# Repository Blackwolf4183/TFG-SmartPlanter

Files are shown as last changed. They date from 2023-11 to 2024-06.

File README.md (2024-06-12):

## Proyecto SmartPlanter

Este README proporciona una visión general del proyecto **SmartPlanter**, que combina tecnologías IoT, cloud computing y machine learning para crear una maceta inteligente con riego automático y monitorización a través de una interfaz web.

## Tabla de Contenidos

- [Sobre el Proyecto](#sobre-el-proyecto)
  - [Objetivos](#objetivos)
  - [Características](#características)
  - [Especificaciones Técnicas](#especificaciones-técnicas)
- [Construido Con](#construido-con)
- [Guía de Inicio](#guía-de-inicio)
  - [Prerequisitos](#prerequisitos)
  - [Instalación](#instalación)
- [Uso](#uso)
- [Roadmap](#roadmap)
- [Licencia](#licencia)
- [Contacto](#contacto)

---

<br />
<div align="center">
  <a href="https://github.com/Blackwolf4183/TFG-SmartPlanter">
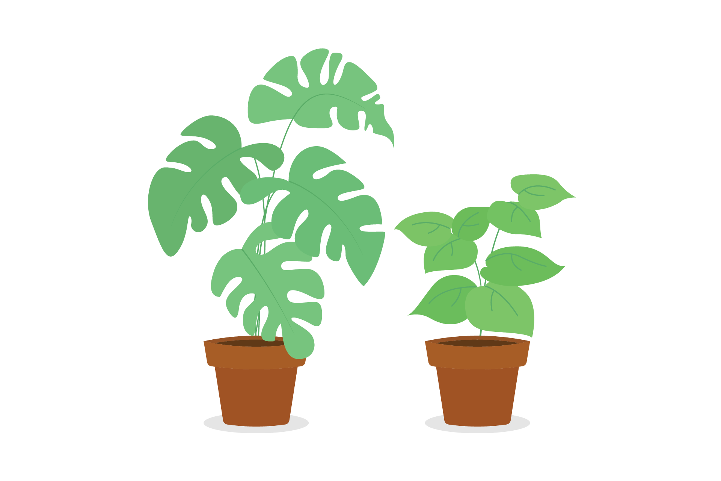
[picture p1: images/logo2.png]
    
  </a>

## Sobre el Proyecto

### Objetivos

El proyecto **SmartPlanter** tiene como objetivo crear una maceta IoT que permite:

- **Riego Automático**: Utiliza sensores para detectar la humedad del suelo y activar el riego cuando sea necesario.
- **Monitorización Remota**: Ofrece una interfaz web para visualizar en tiempo real los datos de la planta como temperatura, luz y humedad.
- **Interfaz Web**: Proporciona una plataforma accesible para configurar y controlar la maceta desde cualquier lugar.

### Características

- **Sensores Integrados**: Monitorea luz, temperatura, humedad del aire y del suelo.
- **Control Automático**: Sistema de riego basado en el análisis de datos en tiempo real.
- **Notificaciones y Alertas**: Envía alertas al usuario sobre el estado de la planta.
- **Machine Learning**: Utiliza modelos predictivos para optimizar el riego y el cuidado de la planta.

### Especificaciones Técnicas

- **Microcontrolador**: ESP32.
- **Plataforma Cloud**: Azure IoT Hub.
- **Base de Datos**: Supabase para el almacenamiento de datos.
- **Lenguajes de Programación**: Python y JavaScript.
- **Frameworks**: Next.js y React.js para la interfaz web.
- **Hardware**: Sensores de humedad, temperatura, y luz.

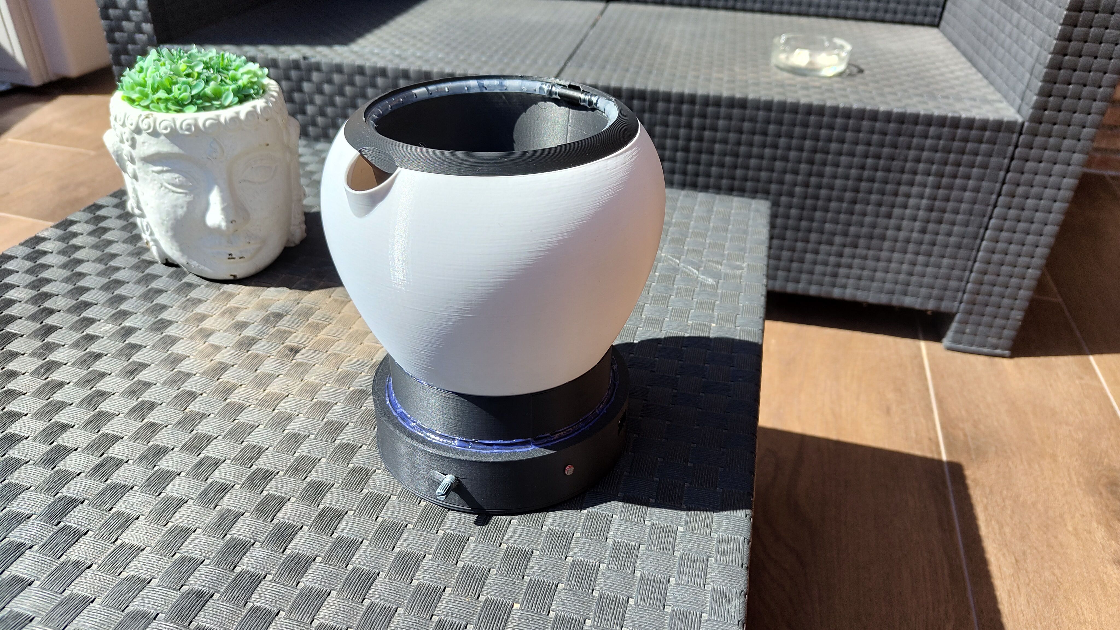
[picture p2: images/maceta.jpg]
Product Name Screen Shot
[](https://example.com)
---

## Construido Con

- [Next.js](https://nextjs.org/) - Framework para React
- [React.js](https://reactjs.org/) - Librería JavaScript para construir interfaces de usuario
- [Python](https://www.python.org/) - Lenguaje de programación para el backend
- [Azure IoT Hub](https://azure.microsoft.com/en-us/services/iot-hub/) - Plataforma de nube para IoT
- [ESP32](https://www.espressif.com/en/products/socs/esp32) - Microcontrolador
- [Supabase](https://supabase.io/) - Base de datos de código abierto

---

## Guía de Inicio

Para obtener una copia local del proyecto y ejecutarlo, sigue estos pasos:

### Prerequisitos

- Node.js y npm (Node Package Manager)
- Python 3.x

Instala Node.js y npm:
```sh
npm install npm@latest -g
```

### Instalación

1. Clona el repositorio:
   ```sh
   git clone https://github.com/Blackwolf4183/TFG-SmartPlanter.git
   ```
2. Navega al directorio del proyecto:
   ```sh
   cd TFG-SmartPlanter/WebApp/Frontend
   ```
3. Instala las dependencias:
   ```sh
   npm install
   ```
---

## Uso

Una vez instalado, puedes ejecutar el proyecto localmente:

1. **Inicia el servidor de desarrollo**:
   ```sh
   npm start
   ```
2. **Accede a la interfaz web** a través de tu navegador en `http://localhost:3000`.

Para más ejemplos y capturas de pantalla, consulta la [documentación](https://github.com/Blackwolf4183/TFG-SmartPlanter).

---

## Roadmap

- [ ] Implementación de sensores adicionales
- [ ] Mejora de la interfaz de usuario
- [ ] Integración con otros servicios cloud
- [ ] Funcionalidades avanzadas de machine learning

Consulta la lista de [issues abiertas](https://github.com/Blackwolf4183/TFG-SmartPlanter/issues) para ver una lista completa de las características propuestas y problemas conocidos.

---

## Licencia

Distribuido bajo la Licencia MIT. Para más información, consulta `LICENSE.txt`.

---

## Contacto

Pablo Pérez Martín - perezmartinpablo@uma.es

Link del Proyecto: [SmartPlanter en GitHub](https://github.com/Blackwolf4183/TFG-SmartPlanter)

---

[product-screenshot]: images/maceta.jpg

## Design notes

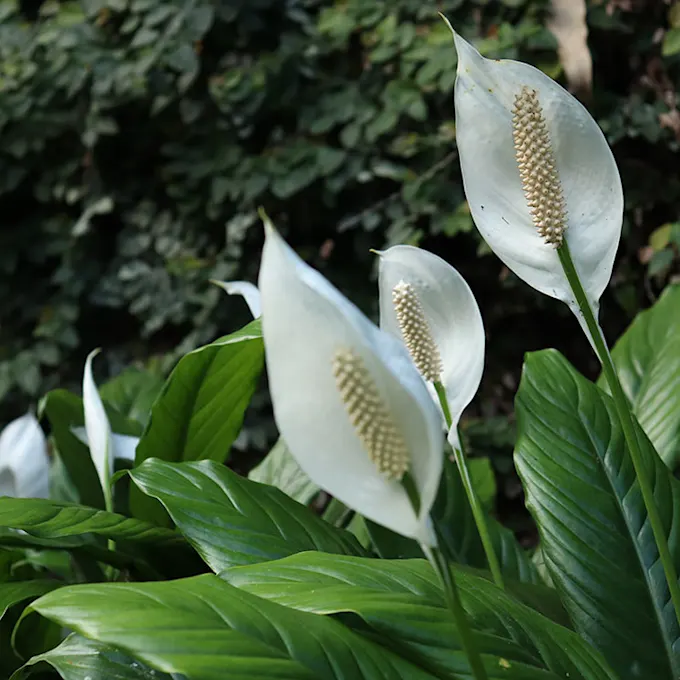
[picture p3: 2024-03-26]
WebApp/Backend/plant_images/espafilito.jpg

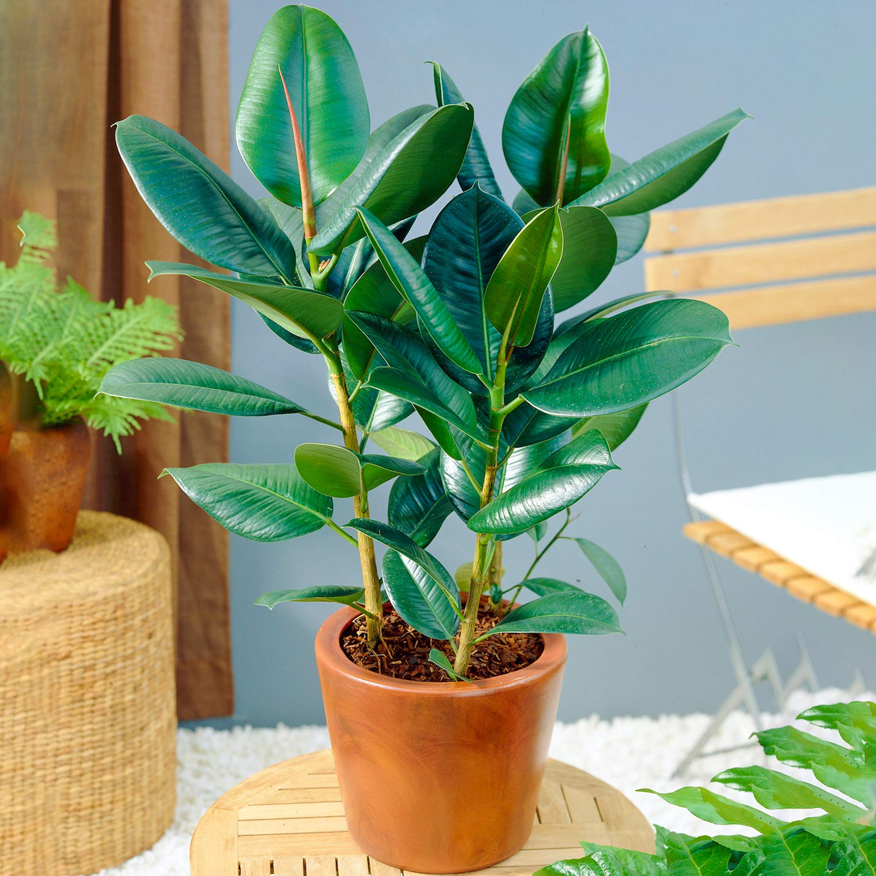
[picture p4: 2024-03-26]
WebApp/Backend/plant_images/ficus_robusta.jpg

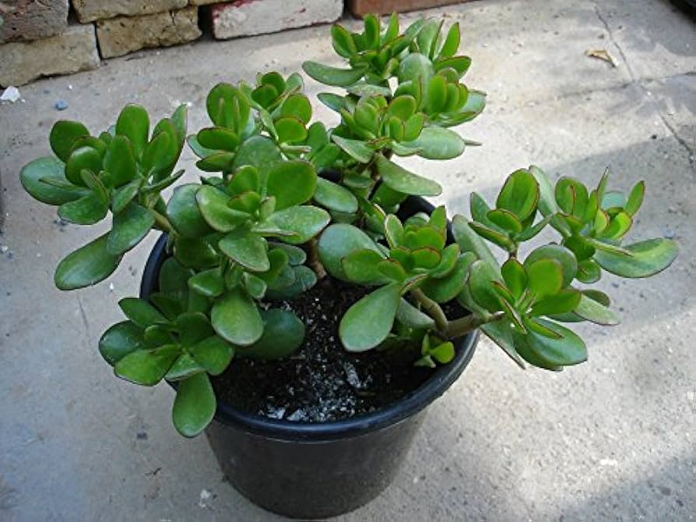
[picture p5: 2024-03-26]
WebApp/Backend/plant_images/arbol_jade.jpg

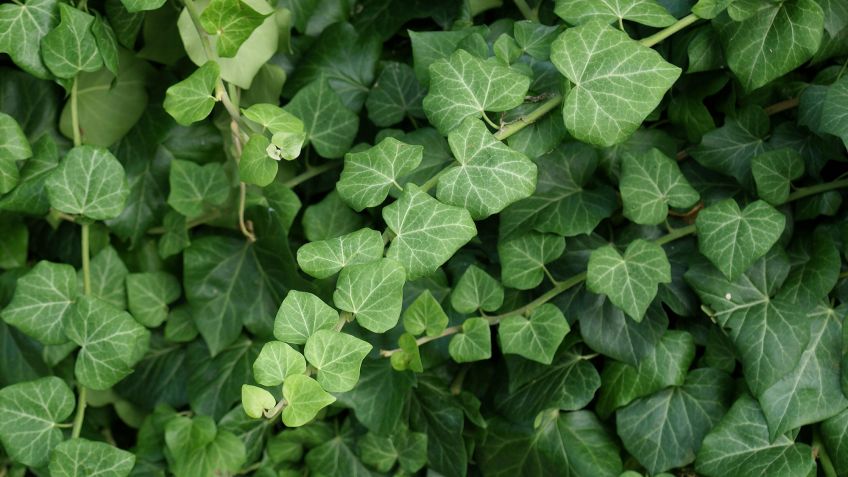
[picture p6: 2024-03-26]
WebApp/Backend/plant_images/hiedrajpg.jpg

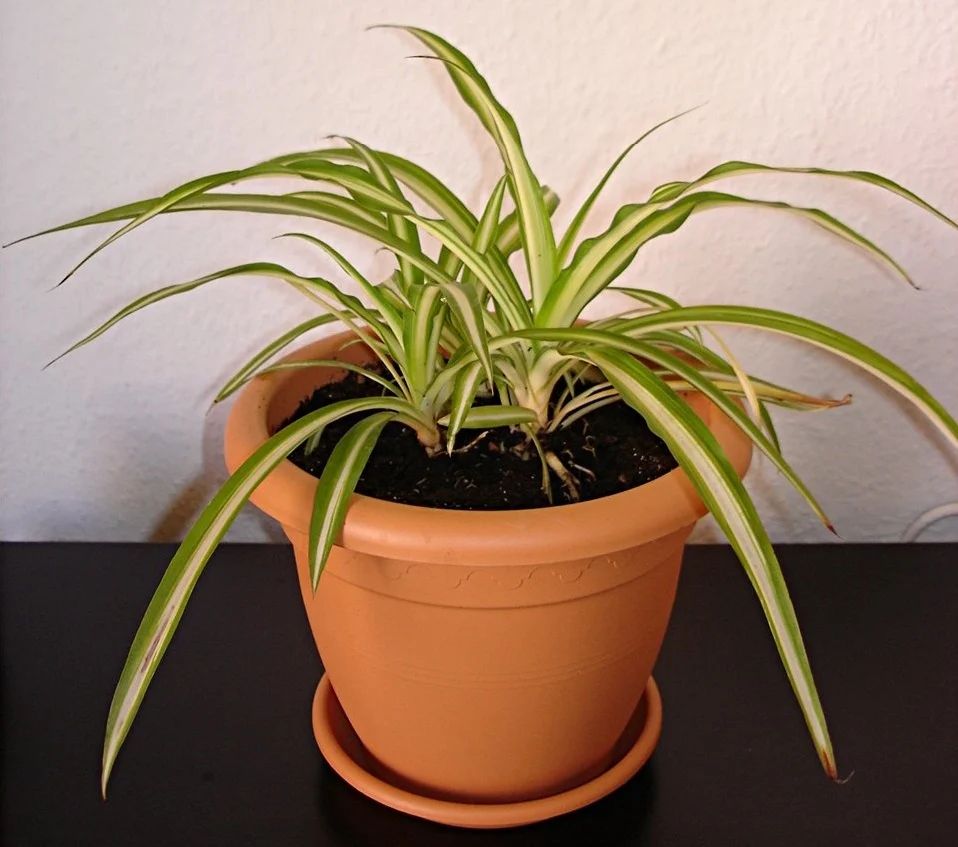
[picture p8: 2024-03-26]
WebApp/Backend/plant_images/malamadre.jpg

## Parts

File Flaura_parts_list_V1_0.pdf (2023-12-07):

Quantity Name | Type | Specification | Additional notes | Example

Parts with water contact
30 cm | Soft Hose Ø4 - Ø2 mm | Material: PVC | outerØ 4 mm, innerØ 2 mm | transparent looks best | https://ebay.us/ntEGVZ
15 cm | Soft Hose Ø7 - Ø5 mm | Material: PVC | outerØ 7 mm, innerØ 5 mm | transparent looks best | https://ebay.us/ntEGVZ
40 cm | Hard Hose Ø4 - Ø2 mm | Material: PTFE, PA?, PU? | outerØ 4 mm, innerØ 2 mm | transparent looks best | https://ebay.us/sQVEkS
1 | T-Connector Hose | T-shape, plastic | outerØ 3.2 mm, innerØ 2.4 mm | Size for link in example is 3.2 mm | https://ebay.us/po10i3
1 | Diaphragm water pump (XYT SP130-XH) | DC 3.7V | Ø20 x 45 mm, Hose connections Ø3.5 mm | 2 visable diaphragms -> suitable for water | https://de.aliexpress.com/item/4000974989453.html?sp (https://de.aliexpress.com/item/4000974989453.html?spm=a2g0x.12010615.8148356.3.2df127f6HkLLrm)
20 mL | Silicon sealant | Sealant for electronics works best (more liquid) | Any, Additional nozzle is very useful | transparent, local hardware store? | https://ebay.us/K84adc

Parts to be soldered

3 | Resistor 100 kOhm | Carbon Film, THT axial | 100 kOhm, 1/4 W | | https://amzn.to/37WaeuK
1 | Resistor 270 Ohm | Carbon Film, THT axial | 270 Ohm, 1/4 W | | https://amzn.to/37WaeuK
1 | Capacitor 100 nF | THT (Pitch 2.54 mm) | 100 nF | | https://ebay.us/KCRTnK
1 | Diode 1N4007 | DO-41, THT | 1 A | | https://ebay.us/PQQNdj
1 | MOSFET IRLZ44N | N-Channel, THT (Pitch 2.54 mm) | Logic level (L) | Don't confuse with : IRFZ44N | https://ebay.us/49aZjN
1 | Push button (XUNPU TS-1002N-08526) | Tactile Switch, THT Side operation | 6 x 7.5 x 8.5 mm, 50 mA | switch lever length: 5 mm | https://lcsc.com/product-detail/Tactile- (https://lcsc.com/product-detail/Tactile-Switches_XUNPU-TS-1002N-08526_C455136.html)
1 | Power switch (SHOU HAN SK12D07VG5) | Toggle Switch, THT Side operation | 4.7 x 8.7 x 9.4 mm, 500 mA | switch lever length: 5 mm | https://lcsc.com/product- (https://lcsc.com/product-detail/Tactile-Switches_XUNPU-TS-1002N-08526_C455136.html) detail/Toggle- (https://lcsc.com/product-detail/Toggle-Switches_SHOU-HAN-SK12D07VG5_C431548.html)
1 | Pin Header Female 12 Pins | THT (Pitch 2.54 mm) | Female, 12 Pins, Height 8.5 mm | | https://ebay.us/DgdD (https://lcsc.com/product-detail/Toggle-Switches_SHOU-HAN-SK12D07VG5_C431548.html)9i
1 | Pin Header Female 16 Pins | THT (Pitch 2.54 mm) | Female, 16 Pins, Height 8.5 mm | | https://ebay.us/DgdD9i
1 | Resistor 33 kOhm | Carbon Film, THT axial | 33 kOhm, 1/4 W | https://amzn.to/37WaeuK

1 | Pin Header Male 3 Pins | THT (Pitch 2.54 mm) | Male, 3 Pins | seperatable into 3 pins | https://ebay.us/TkIBPl
2 | JST Connector Female 2 Pins with Cable | JST Connector Female, PH (Pitch 2.0 mm) | 2 Pins, Cable > 10 cm, AWG24 or AWG22 | Don't use common AWG26 | https://amzn.to/3AY5RMa
1 | JST Connector Female 6 Pins with Cable | JST Connector Female, PH (Pitch 2.0 mm) | 6 Pins, Cable > 30 cm, AWG26 | AWG26 is okay here | https://ebay.us/j6QXjK
2 | JST Connector Male 2 Pins | JST Connector Male, PH (Pitch 2.0 mm) | 2 Pins, Straight | See note on connecter types (last page) | https://amzn.to/3AY5RMa
1 | JST Connector Male 6 Pins | JST Connector Male, PH (Pitch 2.0 mm) | 6 Pins, Straight | See note on connecter types (last page) | https://ebay.us/j6QXjK
1 | Custom PCB (curcuit board) | FR-4, 2 Layers | thickness 1.6 mm, copper weight 1 oz, HASL | custom-made (Gerber file) | Custom PCB manufacturer

Other parts

1 | Li-Ion Battery 3.7V with Connector | 18650 Format, JST Connector Female, PH (Pitch 2.0 mm) | 3.7V, > 2000 mAh, Protection circuitry included | | https://www.adafruit.com/pr
22 | Self tapping Screw Ø3 x 8
mm

Thread forming screw for
thermoplatic (e.g. DIN 9091)
Ø3 x 8 mm, Pan head | https://ebay.us/V4vZwn

oduct/1781 (https://www.adafruit.com/product/1781)

1 | Microcontroller ESP32 | Wemos LOLIN 32 Development board | not the "lite" or "pro" variants, ME6211 LDO | Look at the next page of this file
1 | Capacitve Soil Moisture Sensor | Capacitve Soil Moisture Sensor v1.2 | TL555Q/C/I timer chip, 662K LDO | Look at the next page of this file

Optional
1 | Planter | upperØ 110 mm, lowerØ 85 mm,
| | height 90 mm

Local gardening store

Most things you can currently find in online shops are imitations that look the same at first glance, but some have cheaper electronic components soldered on and do not work properly.

When ordering, it is very important to look carefully at the product images and to check the markings on the electronic components on the circuit board.
If the image quality is so poor, that you cant read the markings - DO NOT ORDER from this store.
If the markings are the ones we are looking for: ask the the store to confirm these markings.

It happend to me, that I didnt recive the exact product as shown in the product pictures, but a diffrent one with the wrong electronic components on it. Even if I ordered from a store from which I initially received a suitable product, I sometimes received a different product with the second order.
I didn't include a link for the ESP32 microcontroller and capacitive soil moisture sensor because I had some bad experiences when ordering them and I don't want to be responsible if this happens to others.

Here's what to look for with each component:

Wemos LOLIN 32 Development board
watch out for undersized LDO's and JST PH connector (watch my Youtube video for more details), https://www.youtube.com/watch?v=GNNzLwCidCE
Good markings: S2RY, S2RK, S2MD, S2PC, S2SL, S2TD (thats an ME6211 LDO)
Bad markings: 4A**, 4B** (thats an XC6204 or XC6205 LDO)

Capacitve Soil Moisture Sensor
watch out for correct 555 Timer chip, present 662k LDO and correct positioning of via hole (watch my Youtube video for more details) https://www.youtube.com/watch?v=IGP38bz-K48
Good markings: TL555C, TL555Q, TL555I
Bad markings: NE555

If you don't want to order all parts individually: I'm thinking of offering all the parts for Flaura as a kit in the future if enough people are interested. To find out, I created a short Google form that you can fill out if you would like to buy such a kit. https://docs.google.com/forms/d/1GDRpVRxuvAgHPNp1CEXVgIKZr3mZhqmVqcmtKoSlDA8

Note on connecter types:
Globally speaking, there seem to be different opinions what male and female connectors are, also among sellers of these parts.

Better make sure the product you want to buy matches those in my videos.

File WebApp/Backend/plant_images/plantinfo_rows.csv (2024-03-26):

id | perenualid | commonname | scientificname | imageurl | watering | sunlight | plantdescription | carelevel | mintemperature | maxtemperature
1 | 7168 | Lengua de trigre | Dracaena trifasciata | https://i.ibb.co/JqQmkMh/lengua-tigre.png | MODERATE | Luz indirecta media a brillante | La Lengua de Tigre (Sansevieria trifasciata) es una planta herbácea perenne conocida por sus hojas puntiagudas y su patrón de rayas distintivo que se asemeja a la piel de un tigre. Es una planta fácil de cuidar y tolerante a condiciones de poca luz y sequía. Su capacidad para purificar el aire la hace ideal para interiores. | LOW | 7 | 21
4 | 7463 | Espatifilo gigante | Spathiphyllum sensation | https://i.ibb.co/TBsBBsr/espafilito.webp | REGULAR | Luz indirecta baja a media | El Espatifilo Gigante (Spathiphyllum) es una planta de interior popular apreciada por sus grandes hojas verdes brillantes y sus elegantes flores blancas en forma de espádice. Es conocida por su capacidad para purificar el aire al eliminar toxinas como el formaldehído y el benceno. | LOW | 18 | 24
9 | 2961 | Ficus Robusta | Ficus Elastica | https://i.ibb.co/tBxFZqx/ficus-robusta.jpg | REGULAR | Luz indirecta brillante | El Ficus Robusta es una planta de interior resistente y de rápido crecimiento conocida por sus hojas grandes y brillantes. Es una planta popular para agregar un toque de verdor a los espacios interiores y se adapta bien a condiciones de luz moderada. Es importante tener cuidado con su savia lechosa, que puede causar irritación en la piel. | MEDIUM | 16 | 21
7 | 2193 | Planta de jade | Crassula ovata | https://i.ibb.co/xjCDPN6/arbol-jade.jpg | INFREQUENT | Luz indirecta brillante | La Planta de Jade es una suculenta perenne conocida por sus hojas carnosas y su tallo grueso y leñoso. Es una planta resistente y fácil de cuidar que se cree que trae buena suerte y prosperidad según la tradición del Feng Shui. Es una excelente opción para principiantes en la jardinería de interior. | LOW | 18 | 24
5 | 728 | Aloe Vera | Aloe barbadensis miller | https://i.ibb.co/rsnytMv/aloevera.jpg | INFREQUENT | Luz indirecta brillante | El Aloe Vera es una planta suculenta resistente y de bajo mantenimiento conocida por sus hojas carnosas y su gel interior curativo. Se ha utilizado durante siglos en la medicina tradicional por sus propiedades calmantes y cicatrizantes para la piel. | LOW | 17 | 27
13 | 5465 | Helecho Espada | Nephrolepis exaltata | https://i.ibb.co/2gktggT/helechoespada.jpg | REGULAR | Luz indirecta media a brillante | El Helecho Espada es una planta de interior popular conocida por sus frondes largas y arqueadas que se asemejan a espadas. Es una planta de bajo mantenimiento que tolera bien la humedad y es ideal para baños y cocinas. Sus hojas verdes brillantes agregan un toque de frescura a cualquier espacio interior. | LOW | 3 | 21
3 | 3849 | Tomate Cherry | Lycopersicum | https://i.ibb.co/1Tnb9C4/cherry.jpg | REGULAR | Sol pleno | El tomate cherry (Solanum lycopersicum var. cerasiforme) es una variedad de tomate de pequeño tamaño con frutos redondos y dulces. Es una planta fácil de cultivar en el jardín o en macetas y produce una abundancia de tomates que son perfectos para ensaladas, bocadillos y conservas. | MEDIUM | 20
10 | 5257 | Costilla de Adán | Monstera Deliciosa | https://i.ibb.co/tbTcmMW/mostrera.webp | REGULAR | Luz indirecta media a brillante | La Costilla de Adán es una planta trepadora perenne conocida por sus grandes hojas perforadas y su aspecto exótico. Es una planta de interior popular que puede alcanzar grandes tamaños y es apreciada por su fácil cuidado y su capacidad para añadir un toque tropical a cualquier espacio. | MEDIUM | 18 | 27
2 | 3013 | Fresas | Fragaria vesca | https://i.ibb.co/fGF7kXV/fresas.jpg | FREQUENT | Sol pleno a sombra parcial | La fresa (Fragaria) es una planta pequeña y perenne que produce frutos rojos dulces y jugosos durante la temporada de crecimiento. Es una planta versátil que puede crecer en macetas o en el suelo y es apreciada por su sabor delicioso y sus beneficios para la salud. | MEDIUM | 14 | 25
15 | 7918 | Reo | Tradescantia spathacea | https://i.ibb.co/b5mCTq4/reo.jpg | REGULAR | Luz indirecta baja a media | El Reo es una planta perenne de interior con hojas gruesas y verdes oscuro con una franja plateada en el centro. Es una planta resistente y fácil de cuidar que es ideal para principiantes en la jardinería de interior. También se conoce como "Moses-in-the-cradle" por sus pequeñas flores blancas que emergen de la base de las hojas. | LOW | 4 | 21
16 | 4456 | Jazmin | Jasminum grandiflorum | https://i.ibb.co/Kr3q3NT/jazmin.jpg | REGULAR | Sol pleno a sombra parcial | El Jazmín es una planta trepadora de floración perenne conocida por sus flores fragantes y atractivas. Sus flores blancas o amarillas desprenden un aroma dulce y embriagador, lo que lo convierte en una opción popular para jardines y áreas al aire libre. El Jazmín florece mejor en climas cálidos y soleados, pero también puede tolerar algo de sombra parcial. | MEDIUM | 3 | 30
12 | 3349 | Hiedra | Hedera helix "Golden Marco" | https://i.ibb.co/jLz5r39/hiedrajpg.jpg | REGULAR | Luz indirecta baja a media | La Hiedra es una planta trepadora perenne apreciada por su follaje denso y su capacidad para cubrir áreas sombrías en el jardín o en el interior. Es una planta versátil que puede crecer en una variedad de condiciones y es ideal para enrejados, macetas colgantes y como cubierta de suelo. | LOW | -1 | 18
11 | 7101 | Romero | Salvia rosmarinus | https://i.ibb.co/Kx22Cg8/romero.jpg | INFREQUENT | Sol pleno | El Romero es un arbusto perenne aromático conocido por sus hojas estrechas y fragantes. Es una planta resistente y de fácil cuidado que es apreciada tanto por sus cualidades culinarias como medicinales. Sus hojas se utilizan comúnmente como condimento en una variedad de platos y también se cree que tienen propiedades estimulantes y revitalizantes. | LOW | -3 | 40
14 | 8755 | Collar de Perlas | Senecio rowleyanus | https://i.ibb.co/4T44K90/rosario.jpg | INFREQUENT | Luz indirecta brillante | El Collar de Perlas es una planta suculenta perenne conocida por sus tallos colgantes y sus hojas redondas y perladas. Es una planta única que es fácil de cuidar y es apreciada por su aspecto decorativo y su capacidad para formar hermosos racimos de perlas. | LOW | 3 | 21
8 | 1847 | Cinta / Malamadre | Chlorophytum comosum | https://i.ibb.co/Gv52Sw9/malamadre.webp | REGULAR | Luz indirecta baja a media | La Cinta, también conocida como Malamadre, es una planta perenne popular por sus largas hojas arqueadas y sus pequeñas flores blancas. Es una planta de bajo mantenimiento que es apreciada por su capacidad para purificar el aire y su facilidad de propagación mediante la formación de hijuelos. | LOW | 15 | 25
6 | 5497 | Albahaca | Ocimum basilicum | https://i.ibb.co/7WVSGCM/albahaca.webp | FREQUENT | Sol pleno | La albahaca es una hierba aromática anual apreciada por su delicioso aroma y sabor distintivo. Es una planta fácil de cultivar en macetas o en el jardín y es un ingrediente versátil en la cocina, utilizado en una variedad de platos como ensaladas, pastas y pesto. | MEDIUM | 20 | 25
17 |  | Asiento de la suegra | Echinocactus grusonii | https://i.ibb.co/ZY5DxBx/asiento-suegra.jpg | INFREQUENT | Luz indirecta baja a brillante | El Asiento de la suegra es una planta suculenta perenne reconocida por sus hojas rígidas y erectas que crecen verticalmente desde el suelo. Es una planta resistente y tolerante a la sequía que es ideal para interiores debido a su capacidad para prosperar en condiciones de poca luz. Además, se cree que purifica el aire al absorber toxinas y liberar oxígeno durante la noche. | LOW | -7

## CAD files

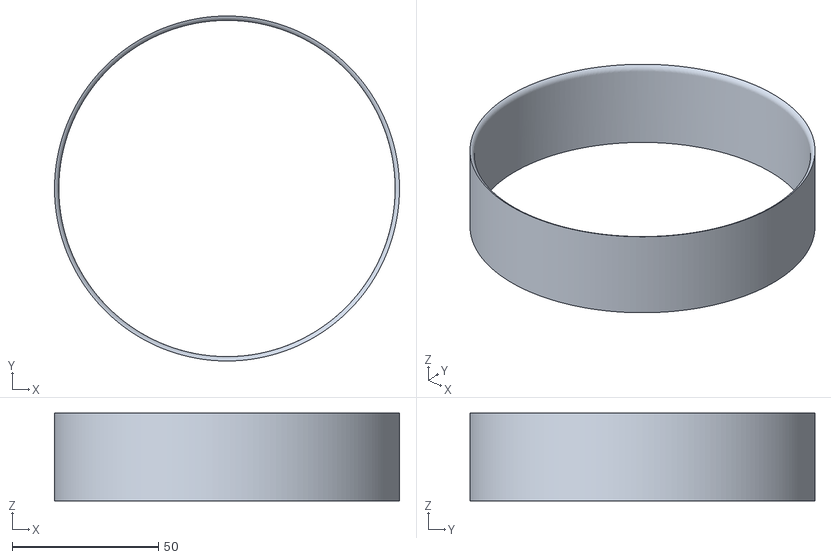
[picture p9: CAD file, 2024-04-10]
Hardware/Embellecedor.stl
118.0 x 118.0 x 30.0

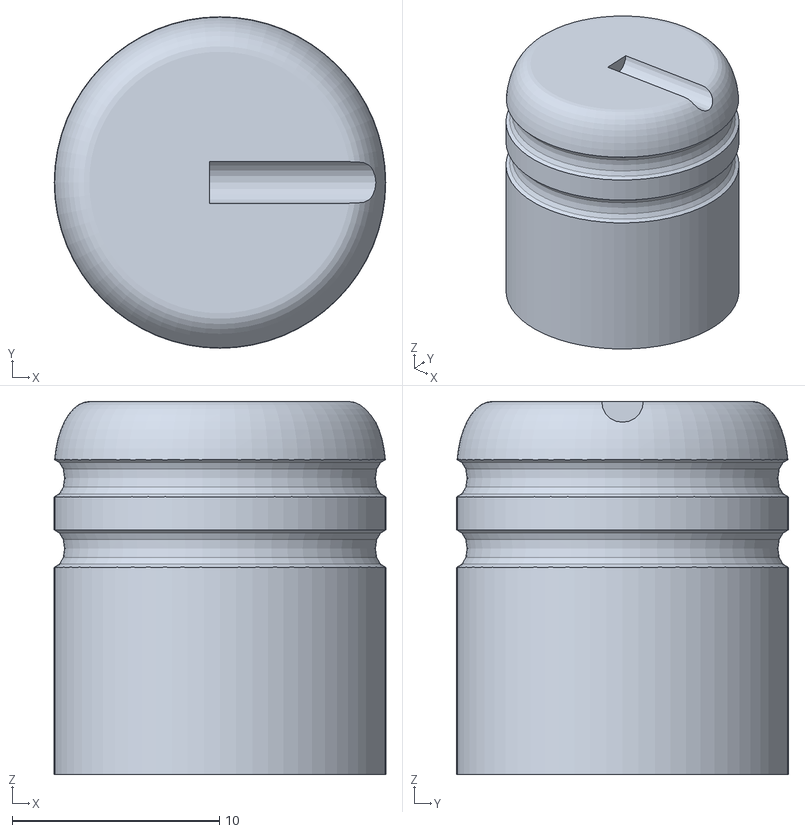
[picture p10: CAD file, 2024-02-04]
Hardware/PotentiometerKnob/ring_Guitar_Amp_Knob.stl
16.0 x 16.0 x 18.0

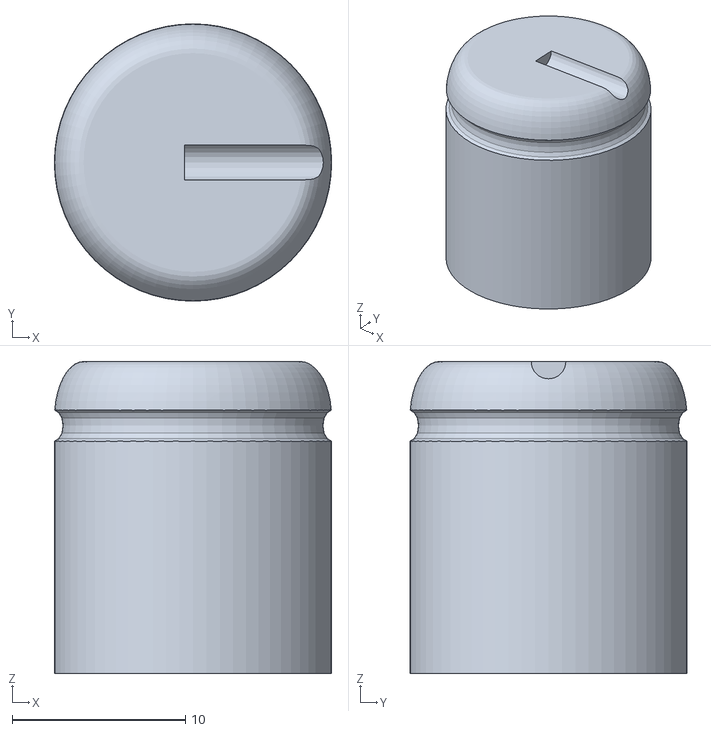
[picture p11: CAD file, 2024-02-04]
Hardware/PotentiometerKnob/Guitar_Amp_Knob-1_ring_bell.stl
16.0 x 16.0 x 18.0

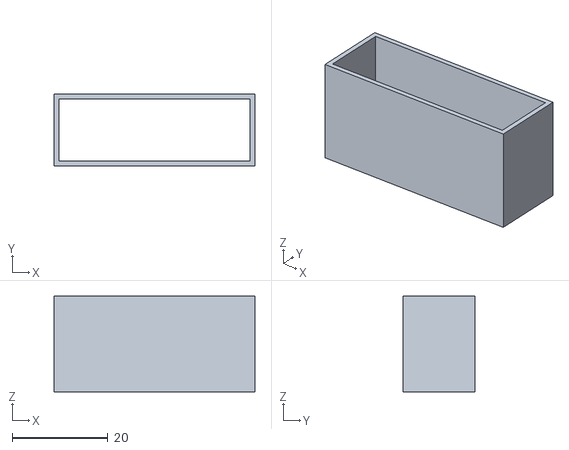
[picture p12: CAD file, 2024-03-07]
Hardware/ResinHolderHumiditySensor.stl
42.0 x 15.0 x 20.0

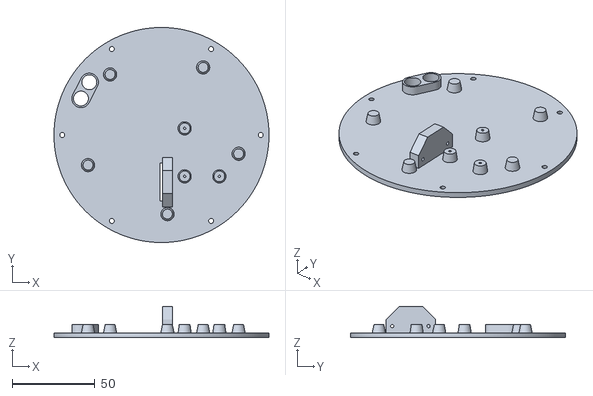
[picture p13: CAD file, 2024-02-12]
Hardware/BottomPlateSmartPlanter v5.stl
130.0 x 130.0 x 19.0

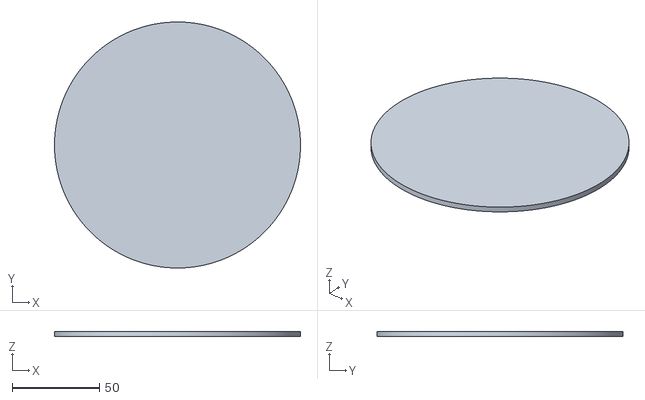
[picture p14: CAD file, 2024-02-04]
Hardware/ElectronicsCover.stl
141.0 x 141.0 x 3.00

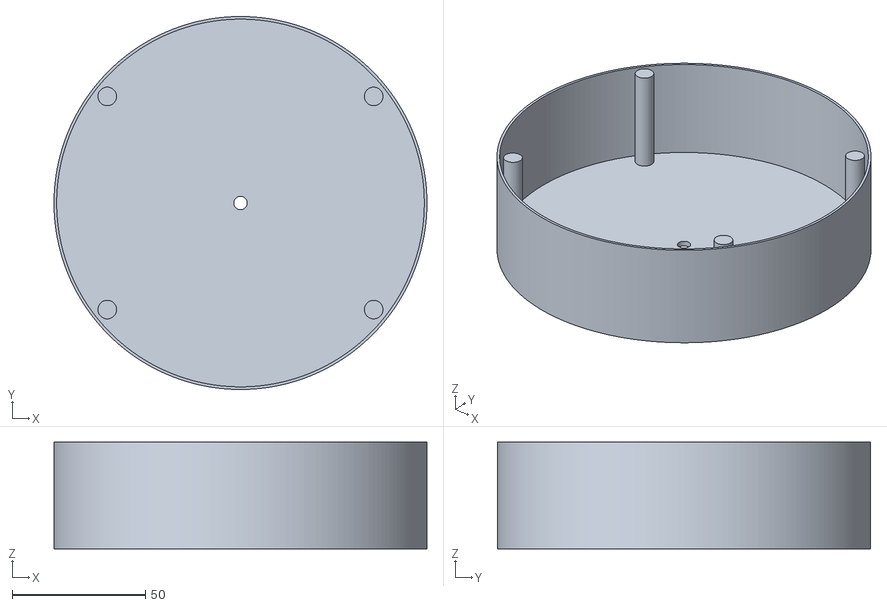
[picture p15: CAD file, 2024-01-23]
Hardware/SmartPlanterComponentsHolderV2.stl
140.0 x 140.0 x 40.0

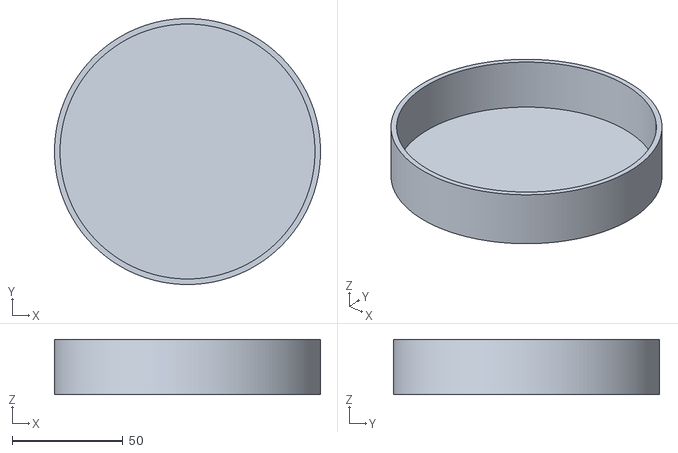
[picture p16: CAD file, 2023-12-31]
Hardware/ComponentsBody.stl
120.0 x 120.0 x 25.0

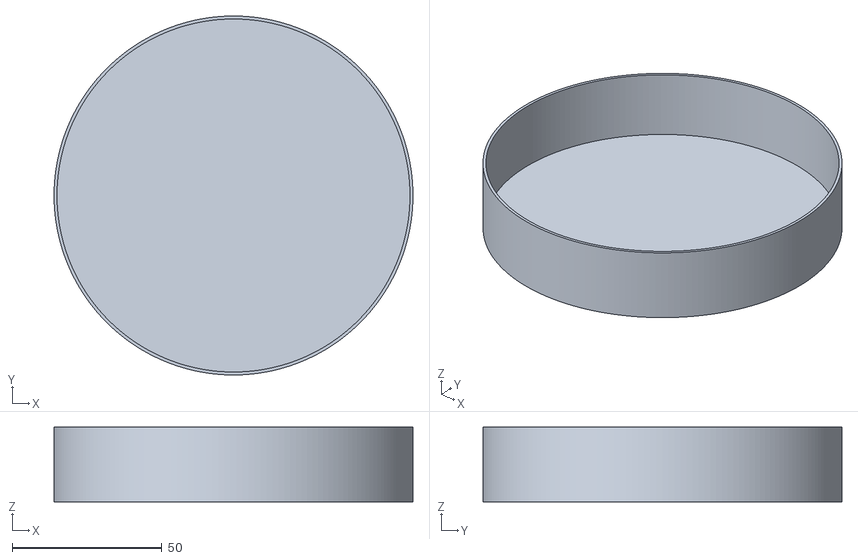
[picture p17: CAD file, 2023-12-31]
Hardware/ComponentsBodyv2.stl
120.0 x 120.0 x 25.0

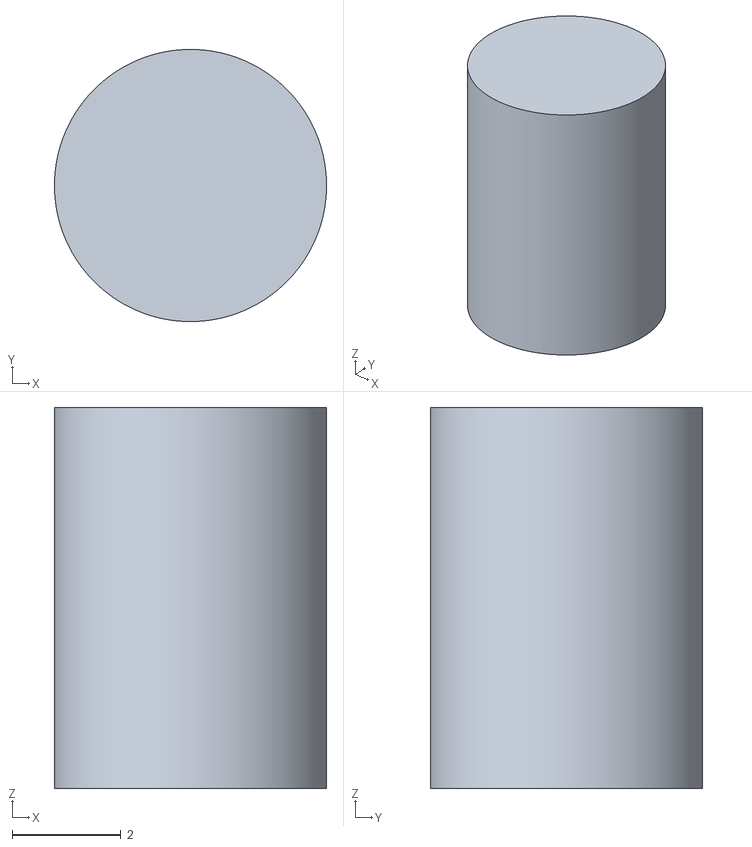
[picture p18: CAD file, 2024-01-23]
Hardware/ScrewSupport.stl
5.00 x 5.00 x 7.00

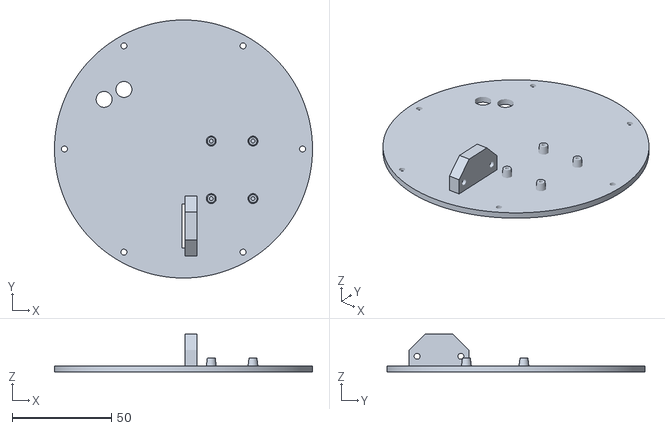
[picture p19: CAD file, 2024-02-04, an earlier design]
Hardware/BottomPlateSmartPlanter v1.stl
130.0 x 130.0 x 19.0

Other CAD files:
Hardware/PotentiometerKnob/Guitar_Amp_Knob-2_ring_bell.stl
Hardware/PotentiometerKnob/Guitar_Amp_Knob-3_ring_bell.stl
Hardware/BottomPlateSmartPlanter v2.stl
Hardware/BottomPlateSmartPlanter v3.stl
Hardware/BottomPlateSmartPlanter v4.stl

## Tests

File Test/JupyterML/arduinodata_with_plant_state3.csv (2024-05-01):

id | soilmoisture | temperature | airhumidity | lightlevel | irrigationamount | timestamp | deviceid | state
846 | 93 | 24.9 | 23 | 67 | 0 | 2024-04-30 18:21:50.105699 | 1 | 3
845 | 92 | 24.9 | 22 | 73 | 0 | 2024-04-30 17:48:53.744508 | 1 | 3
844 | 93 | 24.8 | 19 | 74 | 0 | 2024-04-30 16:48:39.98856 | 1 | 3
843 | 93 | 23.8 | 19 | 77 | 0 | 2024-04-30 16:18:10.850507 | 1 | 3
842 | 93 | 22.3 | 20 | 76 | 0 | 2024-04-30 15:47:52.843476 | 1 | 3
841 | 93 | 22 | 20 | 78 | 0 | 2024-04-30 15:19:31.290547 | 1 | 3
840 | 94 | 23.4 | 46 | 1 | 0 | 2024-04-29 22:22:50.759753 | 1 | 0
839 | 94 | 23.9 | 46 | 1 | 0 | 2024-04-29 21:54:18.746394 | 1 | 0
838 | 94 | 24.2 | 46 | 1 | 0 | 2024-04-29 21:25:49.525343 | 1 | 0
837 | 94 | 24.4 | 44 | 23 | 0 | 2024-04-29 20:57:03.749554 | 1 | 0
836 | 94 | 24.3 | 41 | 61 | 0 | 2024-04-29 20:28:34.21727 | 1 | 0
835 | 94 | 24.4 | 40 | 77 | 0 | 2024-04-29 19:59:53.968846 | 1 | 0
834 | 94 | 24.6 | 38 | 77 | 0 | 2024-04-29 19:31:13.671305 | 1 | 0
833 | 94 | 25.7 | 35 | 60 | 0 | 2024-04-29 19:02:52.717358 | 1 | 0
832 | 94 | 27 | 33 | 54 | 0 | 2024-04-29 18:34:17.426176 | 1 | 0
831 | 93 | 27.4 | 33 | 75 | 0 | 2024-04-29 18:05:42.961723 | 1 | 0
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

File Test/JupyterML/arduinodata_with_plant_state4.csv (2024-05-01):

id | soilmoisture | temperature | airhumidity | lightlevel | irrigationamount | timestamp | deviceid | state
892 | 90 | 28.8 | 23 | 80 | 0 | 2024-05-01 16:48:28.804959 | 1 | 3
891 | 90 | 29 | 24 | 84 | 0 | 2024-05-01 16:19:47.385657 | 1 | 3
890 | 91 | 28.9 | 27 | 86 | 0 | 2024-05-01 15:51:07.664102 | 1 | 3
889 | 88 | 28 | 30 | 85 | 0 | 2024-05-01 15:22:47.874908 | 1 | 3
888 | 91 | 26.6 | 32 | 87 | 0 | 2024-05-01 14:53:34.880526 | 1 | 3
887 | 91 | 26.7 | 33 | 87 | 0 | 2024-05-01 14:24:52.39968 | 1 | 3
886 | 91 | 26.8 | 36 | 79 | 0 | 2024-05-01 13:56:02.541658 | 1 | 3
885 | 91 | 26.6 | 39 | 80 | 0 | 2024-05-01 13:27:30.899258 | 1 | 3
884 | 91 | 26 | 39 | 83 | 0 | 2024-05-01 12:58:40.133183 | 1 | 3
883 | 92 | 25.5 | 40 | 81 | 0 | 2024-05-01 12:29:38.678179 | 1 | 3
882 | 92 | 23.8 | 47 | 81 | 0 | 2024-05-01 12:00:58.314041 | 1 | 3
881 | 93 | 23.7 | 47 | 79 | 0 | 2024-05-01 11:32:27.516267 | 1 | 3
880 | 93 | 21 | 57 | 80 | 0 | 2024-05-01 11:03:44.074843 | 1 | 3
879 | 93 | 20.1 | 58 | 75 | 0 | 2024-05-01 10:34:52.538903 | 1 | 3
878 | 94 | 20 | 57 | 64 | 0 | 2024-05-01 10:06:13.879954 | 1 | 3
877 | 94 | 20 | 56 | 64 | 0 | 2024-05-01 09:37:42.46044 | 1 | 3
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

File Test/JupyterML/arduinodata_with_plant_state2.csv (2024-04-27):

id | soilmoisture | temperature | airhumidity | lightlevel | irrigationamount | timestamp | deviceid | state
701 | 86 | 23.8 | 26 | 1 | 3750 | 2024-04-26 23:44:05.022556 | 1 | 0
700 | 86 | 24.1 | 24 | 1 | 0 | 2024-04-26 23:15:24.367992 | 1 | 0
699 | 86 | 24.4 | 20 | 1 | 0 | 2024-04-26 22:46:54.191467 | 1 | 0
698 | 86 | 24.7 | 17 | 1 | 0 | 2024-04-26 22:18:22.9454 | 1 | 0
697 | 85 | 25 | 16 | 1 | 0 | 2024-04-26 21:49:41.969129 | 1 | 0
696 | 85 | 25.4 | 15 | 1 | 0 | 2024-04-26 21:21:11.480919 | 1 | 0
695 | 85 | 25.9 | 14 | 26 | 0 | 2024-04-26 20:52:30.559199 | 1 | 0
694 | 85 | 26.2 | 13 | 49 | 0 | 2024-04-26 20:23:58.548343 | 1 | 0
693 | 85 | 26.3 | 12 | 70 | 0 | 2024-04-26 19:55:24.454759 | 1 | 0
692 | 85 | 26.4 | 11 | 71 | 0 | 2024-04-26 19:26:42.666519 | 1 | 0
691 | 82 | 26.5 | 11 | 70 | 3750 | 2024-04-26 18:58:24.322414 | 1 | 0
690 | 82 | 26.7 | 11 | 72 | 0 | 2024-04-26 18:29:27.967207 | 1 | 0
689 | 82 | 26.9 | 11 | 72 | 0 | 2024-04-26 18:00:53.958175 | 1 | 0
688 | 82 | 27 | 11 | 74 | 0 | 2024-04-26 17:32:13.810434 | 1 | 0
687 | 82 | 27.1 | 12 | 75 | 0 | 2024-04-26 17:03:43.558701 | 1 | 0
686 | 82 | 27.2 | 13 | 77 | 0 | 2024-04-26 16:35:02.640759 | 1 | 0
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

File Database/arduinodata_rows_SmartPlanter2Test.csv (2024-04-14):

id | soilmoisture | temperature | airhumidity | lightlevel | waterlevel | irrigationamount | timestamp | clientid
69 | 18 | 18.4 | 57 | 64 | 0 | 3466 | 2024-01-24 17:49:43.096873 | SmartPlanter2Test
70 | 18 | 18.7 | 57 | 64 | 0 | 3466 | 2024-01-24 17:49:49.45887 | SmartPlanter2Test
71 | 18 | 19.6 | 56 | 17 | 0 | 5460 | 2024-01-24 17:50:11.626997 | SmartPlanter2Test
72 | 18 | 20.6 | 54 | 64 | 0 | 5460 | 2024-01-24 17:50:23.56819 | SmartPlanter2Test
73 | 70 | 21.1 | 52 | 4 | 0 | 5460 | 2024-01-24 17:50:51.371287 | SmartPlanter2Test
74 | 76 | 21.5 | 51 | 7 | 0 | 5460 | 2024-01-24 17:51:12.54769 | SmartPlanter2Test
75 | 16 | 19.8 | 41 | 1 | 0 | 5466 | 2024-01-26 13:30:24.254853 | SmartPlanter2Test
76 | 16 | 20.2 | 41 | 1 | 0 | 5466 | 2024-01-26 13:30:45.655488 | SmartPlanter2Test
77 | 16 | 21.1 | 39 | 1 | 0 | 5466 | 2024-01-26 13:31:06.926335 | SmartPlanter2Test
78 | 16 | 22 | 37 | 1 | 0 | 5466 | 2024-01-26 13:31:28.180464 | SmartPlanter2Test
79 | 16 | 22.4 | 36 | 74 | 0 | 5466 | 2024-01-26 13:31:49.584066 | SmartPlanter2Test
80 | 16 | 26 | 21 | 1 | 0 | 5466 | 2024-01-26 13:48:40.047261 | SmartPlanter2Test
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

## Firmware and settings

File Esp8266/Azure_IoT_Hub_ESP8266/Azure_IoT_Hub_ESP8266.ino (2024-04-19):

#pragma region Libraries

// C99 libraries
#include <cstdlib>
#include <stdbool.h>
#include <string.h>
#include <time.h>

// Libraries for MQTT client, WiFi connection and SAS-token generation.
#include <ESP8266WiFi.h>
#include <PubSubClient.h>
#include <WiFiClientSecure.h>
#include <base64.h>
#include <bearssl/bearssl.h>
#include <bearssl/bearssl_hmac.h>
#include <libb64/cdecode.h>
#include <ArduinoJson.h>
#include <ESP8266HTTPClient.h>

// Azure IoT SDK for C includes
#include <az_core.h>
#include <az_iot.h>
#include <azure_ca.h>

// Additional sample headers
#include "iot_configs.h"

//Sensors libraries
#include <DHT.h>

#pragma endregion Libraries

#pragma region process defined variables
// When developing for your own Arduino-based platform,
// please follow the format '(ard;<platform>)'.
#define AZURE_SDK_CLIENT_USER_AGENT "c%2F" AZ_SDK_VERSION_STRING "(ard;esp8266)"

// Utility macros and defines
#define sizeofarray(a) (sizeof(a) / sizeof(a[0]))
#define ONE_HOUR_IN_SECS 3600
#define NTP_SERVERS "pool.ntp.org", "time.nist.gov"
#define MQTT_PACKET_SIZE 1024
#pragma endregion process defined variables

#define MIN_ANALOG 0
#define MAX_ANALOG 1023
#define MAX_WATERING_TIME 12500 //In milliseconds
#define AIR_VALUE 500//Values used to compare the capacitive soil moisture sensor values
#define WATER_VALUE 100

// Pins used 
#define DHTTYPE DHT11
#define DHTPIN 2 //D4
#define POWERSOILSENSORPIN 4 //D2
#define POWERPHOTOSENSORPIN 5 //D1
#define POWERPOTENTIOMETERPIN 12 //D6
#define BUTTONPIN 14 //D5
#define RELAYPIN 13 //D7
#define ANALOGPIN A0

#pragma region IoT_configs to variables

// Translate iot_configs.h defines into variables used by the sample
static const char* ssid = IOT_CONFIG_WIFI_SSID;
static const char* password = IOT_CONFIG_WIFI_PASSWORD;
static const char* host = IOT_CONFIG_IOTHUB_FQDN;
static const char* device_id = IOT_CONFIG_DEVICE_ID;
static const char* device_key = IOT_CONFIG_DEVICE_KEY;
static const char* server_name = SMARTPLANTER_API;
static const int port = 8883;

#pragma endregion IoT_configs to variables

#pragma region memory allocation for variables

// Memory allocated for the sample's variables and structures.
static WiFiClientSecure wifi_client;
static X509List cert((const char*)ca_pem);
static PubSubClient mqtt_client(wifi_client);
static az_iot_hub_client client;
static char sas_token[200];
static uint8_t signature[512];
static unsigned char encrypted_signature[32];
static char base64_decoded_device_key[32];
static unsigned long next_telemetry_send_time_ms = 0;
static char telemetry_topic[128];
static uint8_t telemetry_payload[100];
static uint32_t telemetry_send_count = 0;

#pragma endregion memory allocation for variables

//Https Request certificate
static X509List cert2((const char*)ca_pem);

#pragma region Auxiliary functions

// Auxiliary functions

static void connectToWiFi()
{
  
  Serial.println();
  Serial.print("Connecting to WIFI SSID ");
  Serial.println(ssid);

  WiFi.mode(WIFI_STA);
  WiFi.disconnect();
  delay(100);
  WiFi.begin(ssid, password);
  while (WiFi.status() != WL_CONNECTED)
  {
    delay(500);
    Serial.print(".");
  }

  Serial.print("WiFi connected, IP address: ");
  Serial.println(WiFi.localIP());
}

static void initializeTime()
{
  Serial.print("Setting time using SNTP");

  configTime(-5 * 3600, 0, NTP_SERVERS);
  time_t now = time(NULL);
  while (now < 1510592825)
  {
    delay(500);
    Serial.print(".");
    now = time(NULL);
  }
  Serial.println("done!");
}

static char* getCurrentLocalTimeString()
{
  time_t now = time(NULL);
  return ctime(&now);
}

static void printCurrentTime()
{
  Serial.print("Current time: ");
  Serial.print(getCurrentLocalTimeString());
}

void receivedCallback(char* topic, byte* payload, unsigned int length)
{
  Serial.print("Received [");
  Serial.print(topic);
  Serial.print("]: ");
  for (int i = 0; i < length; i++)
  {
    Serial.print((char)payload[i]);
  }
  Serial.println("");
}

static void initializeClients()
{
  az_iot_hub_client_options options = az_iot_hub_client_options_default();
  options.user_agent = AZ_SPAN_FROM_STR(AZURE_SDK_CLIENT_USER_AGENT);

  wifi_client.setTrustAnchors(&cert);
  if (az_result_failed(az_iot_hub_client_init(
          &client,
          az_span_create((uint8_t*)host, strlen(host)),
          az_span_create((uint8_t*)device_id, strlen(device_id)),
          &options)))
  {
    Serial.println("Failed initializing Azure IoT Hub client");
    return;
  }

  mqtt_client.setServer(host, port);
  mqtt_client.setCallback(receivedCallback);
}

/*
 * @brief           Gets the number of seconds since UNIX epoch until now.
 * @return uint32_t Number of seconds.
 */
static uint32_t getSecondsSinceEpoch() { return (uint32_t)time(NULL); }

static int generateSasToken(char* sas_token, size_t size)
{
  az_span signature_span = az_span_create((uint8_t*)signature, sizeofarray(signature));
  az_span out_signature_span;
  az_span encrypted_signature_span
      = az_span_create((uint8_t*)encrypted_signature, sizeofarray(encrypted_signature));

  uint32_t expiration = getSecondsSinceEpoch() + ONE_HOUR_IN_SECS;

  // Get signature
  if (az_result_failed(az_iot_hub_client_sas_get_signature(
          &client, expiration, signature_span, &out_signature_span)))
  {
    Serial.println("Failed getting SAS signature");
    return 1;
  }

  // Base64-decode device key
  int base64_decoded_device_key_length
      = base64_decode_chars(device_key, strlen(device_key), base64_decoded_device_key);

  if (base64_decoded_device_key_length == 0)
  {
    Serial.println("Failed base64 decoding device key");
    return 1;
  }

  // SHA-256 encrypt
  br_hmac_key_context kc;
  br_hmac_key_init(
      &kc, &br_sha256_vtable, base64_decoded_device_key, base64_decoded_device_key_length);

  br_hmac_context hmac_ctx;
  br_hmac_init(&hmac_ctx, &kc, 32);
  br_hmac_update(&hmac_ctx, az_span_ptr(out_signature_span), az_span_size(out_signature_span));
  br_hmac_out(&hmac_ctx, encrypted_signature);

  // Base64 encode encrypted signature
  String b64enc_hmacsha256_signature = base64::encode(encrypted_signature, br_hmac_size(&hmac_ctx));

  az_span b64enc_hmacsha256_signature_span = az_span_create(
      (uint8_t*)b64enc_hmacsha256_signature.c_str(), b64enc_hmacsha256_signature.length());

  // URl-encode base64 encoded encrypted signature
  if (az_result_failed(az_iot_hub_client_sas_get_password(
          &client,
          expiration,
          b64enc_hmacsha256_signature_span,
          AZ_SPAN_EMPTY,
          sas_token,
          size,
          NULL)))
  {
    Serial.println("Failed getting SAS token");
    return 1;
  }

  return 0;
}

static int connectToAzureIoTHub()
{
  size_t client_id_length;
  char mqtt_client_id[128];
  if (az_result_failed(az_iot_hub_client_get_client_id(
          &client, mqtt_client_id, sizeof(mqtt_client_id) - 1, &client_id_length)))
  {
    Serial.println("Failed getting client id");
    return 1;
  }

  mqtt_client_id[client_id_length] = '\0';

  char mqtt_username[128];
  // Get the MQTT user name used to connect to IoT Hub
  if (az_result_failed(az_iot_hub_client_get_user_name(
          &client, mqtt_username, sizeofarray(mqtt_username), NULL)))
  {
    printf("Failed to get MQTT clientId, return code\n");
    return 1;
  }

  Serial.print("Client ID: ");
  Serial.println(mqtt_client_id);

  Serial.print("Username: ");
  Serial.println(mqtt_username);

  mqtt_client.setBufferSize(MQTT_PACKET_SIZE);

  while (!mqtt_client.connected())
  {
    time_t now = time(NULL);

    Serial.print("MQTT connecting ... ");

    if (mqtt_client.connect(mqtt_client_id, mqtt_username, sas_token))
    {
      Serial.println("connected.");
    }
    else
    {
      Serial.print("failed, status code =");
      Serial.print(mqtt_client.state());
      Serial.println(". Trying again in 5 seconds.");
      // Wait 5 seconds before retrying
      delay(5000);
    }
  }

  mqtt_client.subscribe(AZ_IOT_HUB_CLIENT_C2D_SUBSCRIBE_TOPIC);

  return 0;
}

static void establishConnection()
{
  connectToWiFi();
  initializeTime();
  printCurrentTime();
  initializeClients();

  // The SAS token is valid for 1 hour by default in this sample.
  // After one hour the sample must be restarted, or the client won't be able
  // to connect/stay connected to the Azure IoT Hub.
  if (generateSasToken(sas_token, sizeofarray(sas_token)) != 0)
  {
    Serial.println("Failed generating MQTT password");
  }
  else
  {
    connectToAzureIoTHub();
  }

}

static char* getTelemetryPayload()
{
  az_span temp_span = az_span_create(telemetry_payload, sizeof(telemetry_payload));
  temp_span = az_span_copy(temp_span, AZ_SPAN_FROM_STR("{ \"msgCount\": "));
  (void)az_span_u32toa(temp_span, telemetry_send_count++, &temp_span);
  temp_span = az_span_copy(temp_span, AZ_SPAN_FROM_STR(" }"));
  temp_span = az_span_copy_u8(temp_span, '\0');

  return (char*)telemetry_payload;
}

#pragma endregion Auxiliary functions

//Given an error message string sends that error to the IoT Hub to store it in the logs
static void sendError(String errorMessage)
{
  Serial.print(millis());
  Serial.print(" ESP8266 Sending error . . . ");
  
  if (az_result_failed(az_iot_hub_client_telemetry_get_publish_topic(&client, NULL, telemetry_topic, sizeof(telemetry_topic), NULL)))
  {
    Serial.println("Failed publishing into topic");
    return;
  }

  // Use the function arguments in the JSON data
  String jsonData = String("{\"ErrorMessage\":\"") + errorMessage + "\"}";

  mqtt_client.publish(telemetry_topic, jsonData.c_str(), false);
  Serial.println("OK");
  delay(100);
}

String irrigationError;

//Performs a call to the API and returns -1 if the plant should not be watered, else returns a number indicating the number of milliseconds the pump will be active for
static int getIrrigationInfoFromServer(int soilMoisturePercent)
{
  if(WiFi.status()== WL_CONNECTED){
    WiFiClientSecure client;
    HTTPClient http;


    //Certificate for secure http request
    initializeTime();
    client.setTrustAnchors(&cert2);

    String serverPath = String(server_name) + "/esp/irrigate" + "?client_id=" + String(device_id) + "&soil_moisture=" + soilMoisturePercent;

    // Your Domain name with URL path or IP address with path
    http.begin(client, serverPath);
    
    // Send HTTP GET request
    //TODO: if server takes a bit from sleep then the request times out, make it wait longer
    int httpResponseCode = http.GET();
    
    if (httpResponseCode>0) {
      Serial.print("HTTP Response code: ");
      Serial.println(httpResponseCode);
      String payload = http.getString();
      Serial.println(payload);

      // Create a JSON object
      StaticJsonDocument<200> doc;
      
      // Parse the JSON payload
      DeserializationError error = deserializeJson(doc, payload);
      
      // Check for parsing errors
      if (error) {
        Serial.print("deserializeJson() failed: ");
        Serial.println(error.c_str());
        irrigationError = "Error when trying to deserialize JSON from API";
        http.end();
        return -1; // Return -1 to indicate an error
      }

      // Extract the value of shouldIrrigate
      bool shouldIrrigate = doc["shouldIrrigate"];

      // If shouldIrrigate is true, return the irrigation amount as an integer
      if (shouldIrrigate) {
        // Convert the irrigation amount to an integer
        float irrigationAmountFloat = doc["irrigationAmount"];
        int irrigationAmountInt = static_cast<int>(irrigationAmountFloat);
        return irrigationAmountInt;
      } else {
        return 0; // Return 0 if shouldIrrigate is false
      }

    }
    else {
      Serial.print("Error code: ");
      Serial.println(httpResponseCode);
      irrigationError = "Error when trying to communicate with API, error code: " + String(httpResponseCode);
      return -1;
      http.end();
    }
    // Free resources
    http.end();
  }
  else {
    Serial.println("WiFi Disconnected");
  }

  return -1;
}

static void sendTelemetry(int wateringMilliseconds, int lightLevelValue, int soilMoisturePercentage, float temperature, float humidity)
{
  Serial.print(millis());
  Serial.print(" ESP8266 Sending telemetry . . . ");
  
  if (az_result_failed(az_iot_hub_client_telemetry_get_publish_topic(&client, NULL, telemetry_topic, sizeof(telemetry_topic), NULL)))
  {
    Serial.println("Failed publishing into topic");
    return;
  }

  // Use the function arguments in the JSON data
  String jsonData = "{\"SoilMoisture\":" + String(soilMoisturePercentage) +
                    ",\"Temperature\":" + String(temperature) +
                    ",\"AirHumidity\":" + String(humidity) +
                    ",\"LightLevel\":" + String(lightLevelValue) +
                    ",\"WaterLevel\":" + "0" + //TODO: maybe in a future add water level
                    ",\"IrrigationTime\":" + String(wateringMilliseconds) + "}";

  mqtt_client.publish(telemetry_topic, jsonData.c_str(), false);
  Serial.println("OK");
  delay(100);
}


// Arduino setup and loop main functions.
DHT dht(DHTPIN, DHTTYPE);

//Variables to collect sensor measurements
int wateringMilliseconds;
int lightLevelPercent;
int soilMoisturePercent;
float temperature;
float humidity;

//Main program (this activates each time the esp wakes from deepsleep)
void setup()
{
  
  digitalWrite(RELAYPIN, LOW); 

  pinMode(POWERSOILSENSORPIN, OUTPUT);
  pinMode(POWERPHOTOSENSORPIN, OUTPUT);
  pinMode(POWERPOTENTIOMETERPIN, OUTPUT);
  pinMode(RELAYPIN, OUTPUT);

  //Set relay on low so it doesn't activate the water pump
  digitalWrite(RELAYPIN, LOW);

  dht.begin();

  while (!Serial) { }
  
  Serial.begin(115200);

  Serial.println();Serial.println("---------------------------------");
  Serial.println("ESP wakes up");
  
  //Connect to WiFi
  WiFi.begin(ssid, password);
  Serial.println("Connecting");
  while(WiFi.status() != WL_CONNECTED) {
    delay(500);
    Serial.print(".");
  }
  Serial.println("");
  Serial.print("Connected to WiFi network with IP Address: ");
  Serial.println(WiFi.localIP());
  
  //Get data from sensors and send it to azure
  gatherData();

  //Get watering time from server
  int wateringTimeAPI = getIrrigationInfoFromServer(soilMoisturePercent);

  //Clear variables and connect to mqtt azure
  client = az_iot_hub_client();
  while(!mqtt_client.connected())
  {
    // Check if connected, reconnect if needed.
    establishConnection();
    delay(500);
  }

  // MQTT loop must be called to process Device-to-Cloud and Cloud-to-Device.
  mqtt_client.loop();

  

  //If wateringTime == -1 then the plant should not be watered, just send the measurement of sensors
  if(wateringTimeAPI == -1)
  {
    //Send previos generated error now that we have connection with iot Hub
    sendError(irrigationError);
    sendTelemetry(0, lightLevelPercent, soilMoisturePercent, temperature, humidity);
  }
  else
  {
    Serial.println("Watering the plant for: " + String(wateringTimeAPI) + " milliseconds");
    //Activate the pump for the time supposed to be in the potentiometer
    digitalWrite(RELAYPIN, HIGH);
    delay(wateringTimeAPI); 
    digitalWrite(RELAYPIN, LOW);

    sendTelemetry(wateringTimeAPI, lightLevelPercent, soilMoisturePercent, temperature, humidity);
  }

  deepSleepESP();
}

void deepSleepESP()
{
  digitalWrite(BUTTONPIN, LOW);
  delay(1000);

  Serial.println("Going to sleep 30 minutes");
  //ESP.deepSleep(10e6); //Uncomment this to have the ESP wake up each 10 seconds
  ESP.deepSleep(1800e6); //30 minutes between every wake of the ESP 
}

//Returns number of milliseconds for the relay to be active. If there was an error with the sensors, returns -1.
void gatherData()
{
  int lightLevelValue = analogReadPhotoResistor();

  delay(500);

  int soilMoistureValue = analogReadSoilMoistureSensor();

  delay(500);

  int potentiometerValue = analogReadPotentiometer();

  delay(500);

  digitalWriteLowAll();

  temperature = dht.readTemperature();
  humidity = dht.readHumidity();

  if (isnan(humidity) || isnan(temperature))
  {
    Serial.println("Error de sensor");
    sendError("DHT measurement error.");
    return;
  }

  wateringMilliseconds = (int) ((float) ((float) potentiometerValue / (float) MAX_ANALOG) * MAX_WATERING_TIME);
  soilMoisturePercent = map(soilMoistureValue, AIR_VALUE, WATER_VALUE, 0, 100);
  lightLevelPercent = map(lightLevelValue, 0, 1023, 0, 100);

  //Logs
  Serial.print("Humidity: ");
  Serial.println(humidity);
  Serial.print("Temperature: ");
  Serial.println(temperature);
  Serial.print("Potentiometer: ");
  Serial.println(potentiometerValue);
  Serial.print("Soil Moisture: ");
  Serial.println(soilMoisturePercent);
  Serial.print("Light level: ");
  Serial.println(lightLevelPercent);

}

void digitalWriteLowAll(){
  digitalWrite(POWERPHOTOSENSORPIN, LOW);
  digitalWrite(POWERSOILSENSORPIN, LOW);
  digitalWrite(POWERPOTENTIOMETERPIN, LOW);
  delay(100);
}

int analogReadPhotoResistor() {
  digitalWriteLowAll();
  digitalWrite(POWERPHOTOSENSORPIN, HIGH);
  delay(100);
  return analogRead(ANALOGPIN);
}

int analogReadSoilMoistureSensor() {
  digitalWriteLowAll();
  digitalWrite(POWERSOILSENSORPIN, HIGH);
  delay(100);
  return analogRead(ANALOGPIN);
}

int analogReadPotentiometer() {
  digitalWriteLowAll();
  digitalWrite(POWERPOTENTIOMETERPIN, HIGH);
  delay(100);
  return analogRead(ANALOGPIN);
}

void loop(){}

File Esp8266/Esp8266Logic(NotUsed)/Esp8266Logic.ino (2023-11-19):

#include <ESP8266WiFi.h>
#include <PubSubClient.h>
#include <ArduinoJson.h>
#include "arduino_secrets.h"

// WiFi
const char *ssid = SECRET_SSID; // Enter your WiFi name
const char *password = SECRET_PASS;  // Enter WiFi password

// MQTT Broker
String device_id = "Planter";
const char *mqtt_broker = MQTT_BROKER;
const char *topic = "data";
const char* mqtt_clientId = "Planter";
const char *mqtt_username = MQTT_USER;
const char *mqtt_password = MQTT_PASSWORD;
const int mqtt_port = MQTT_PORT;

WiFiClient espClient;
void callback(char* topic, byte* payload, unsigned int length);
PubSubClient mqtt_client(mqtt_broker, mqtt_port, callback, espClient);

void setup() {
  // Set software serial baud to 115200;
  Serial.begin(115200);
  // connecting to a WiFi network
  WiFi.begin(ssid, password);
  while (WiFi.status() != WL_CONNECTED) {
      delay(500);
      Serial.println("Intentando conectar a red WIFI..");
  }
  Serial.println("Conectado a red wifi");
  //connecting to a mqtt broker
  mqtt_connect();
}

void mqtt_connect(){
// Loop until we're reconnected
  while (!mqtt_client.connected()) {
    Serial.println("Attempting MQTT connection...");
    // Attempt to connect
    //    if (mqtt_client.connect(mqtt_clientId, mqtt_user, mqtt_password)) {
    if (mqtt_client.connect(mqtt_clientId)) {
      Serial.println("MQTT Client Connected");
      mqtt_publish((char*)("Hi from " + device_id).c_str());
      // Subscribe
      mqtt_subscribe(topic);
    } else {
      Serial.print("failed, rc=");
      Serial.print(mqtt_client.state());
      Serial.println(" try again in 5 seconds");
      // Wait 5 seconds before retrying
      delay(5000);
    }
  }
}

void mqtt_publish(char * data) {
  mqtt_connect();
  if (mqtt_client.publish(topic, data))
    Serial.println("Publish \"" + String(data) + "\" ok");
  else
    Serial.println("Publish \"" + String(data) + "\" failed");
}
void mqtt_subscribe(const char * topic) {
  if (mqtt_client.subscribe(topic))
    Serial.println("Subscribe \"" + String(topic) + "\" ok");
  else
    Serial.println("Subscribe \"" + String(topic) + "\" failed");
}


void callback(char* topic, byte* payload, unsigned int length) {
  String command;
  Serial.print("\n\nMessage arrived [");
  Serial.print(topic);
  Serial.println("] ");
  for (int i = 0; i < length; i++)
    command += (char)payload[i];

  if (command.length() > 0)
    Serial.println("Command receive is : " + command);

  DynamicJsonDocument doc(1024);
  deserializeJson(doc, command);
  JsonObject obj = doc.as<JsonObject>();

  
}


void loop() {
  if (!mqtt_client.loop())
    mqtt_connect();

  delay(1000);
}

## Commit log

2023-11-29 Add Model for ArduinoData (Pending to check)
2023-11-29 Arduino function test working
2023-12-07 Sensor testing works with light and temperature sensor
2023-12-10 Working sensor measurements in test file
2023-12-31 Test script can now read potentiometer and button
    [ComponentsBody.stl, ComponentsBodyv2.stl]
2024-01-07 DeepSleep working.
    BUG: Soil moisture readings are off somehow, if done independently they work fine but doing them in sequence does something weird
    [TestArduinoSensors.ino]
2024-01-07 Sensor measurements working
2024-01-23 ESP publishing real sensor data working and also data processing
    May still need to adjust a bit the values to get correct percentages
    [ScrewSupport.stl, SmartPlanterComponentsHolderV2.stl]
2024-01-24 Added error handling in esp and azure function
    [Azure_IoT_Hub_ESP8266_Data_Gather.ino]
2024-02-04 Updated DB Script, backend and frontend initialization
    [BottomPlateSmartPlanter v1.stl, BottomPlateSmartPlanter v2.stl, BottomPlateSmartPlanter v3.stl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]
2024-02-06 Switch backend to FastAPI
2024-02-12 Develop security, device and error routes
    [BottomPlateSmartPlanter v5.stl]
2024-02-26 Modal to ask user device details started
2024-03-01 Link device to user implemented in user interface
2024-03-07 api/plants/irrigation - POST done
    [ResinHolderHumiditySensor.stl]
2024-03-25 Error temperature and watering graphic bentos
2024-03-25 Fix bug with deviceId on cookies
2024-03-26 Mini plants API
    [plantinfo_rows.csv]
2024-04-03 Fixed graph filtering for current date
2024-04-04 DB Backup for important tables, added new enpoints to enable multidevice and minor changes
    [arduinodata_rows_backup_4-4-24.csv, errorlog_rows_4-4-24.csv]
2024-04-08 Https request and mqtt working simultaneously (not the best fix but works at least)
    Data gather should also take watering manually into account
    [Azure_IoT_Hub_ESP8266_Data_Gather.ino]
2024-04-10 Standard script for irrigation working arduino
2024-04-10 Fix API key needed to create device
2024-04-10 Bit more tidying up with the esp code and 3d print to make planter look better
    [Embellecedor.stl]
2024-04-12 A bit more fixing on error graph and added buttons without functionality yet to send feedback to train model
2024-04-14 Fix graphics item bug, added new table for model training in db and implemented deletion of data when user changes plant
    [arduinodata_rows_SmartPlanter2Test.csv, arduinodata_rows_backup_14-4-24.csv]
2024-04-19 Change relay pin
2024-04-27 Set up for LSTM neural network
    [arduinodata_with_plant_state.csv, arduinodata_with_plant_state2.csv]
2024-04-29 Fix on tooltip on training button
2024-05-01 Model training in API
    [arduinodata_with_plant_state.csv, arduinodata_with_plant_state3.csv, arduinodata_with_plant_state4.csv]
